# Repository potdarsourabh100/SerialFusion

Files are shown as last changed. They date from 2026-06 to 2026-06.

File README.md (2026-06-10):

# 🚀 SerialFusion

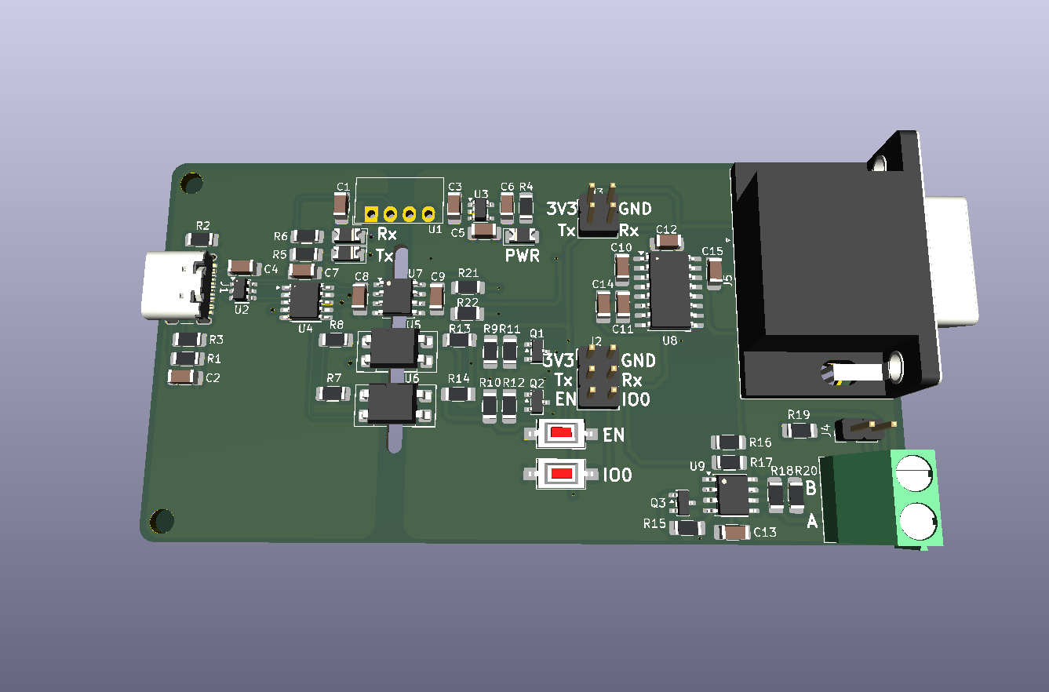
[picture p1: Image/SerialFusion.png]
3D Render


*Universal Isolated USB-to-UART / ESP32 Programmer / RS485 / RS232 Converter*

---

## 📖 Overview

**SerialFusion** is a professional-grade isolated USB communication and programming tool designed for embedded engineers, makers, students, and industrial automation developers.

The board combines multiple serial communication interfaces into a single compact device:

* USB ↔ UART (TTL/CMOS)
* ESP32 Auto Programmer
* USB ↔ RS485 Converter
* USB ↔ RS232 Converter

At its core is the reliable **CH340K USB-UART bridge**, combined with digital isolation, isolated power, industrial-grade transceivers, and ESP32 auto-programming support.

Unlike typical USB-TTL adapters, SerialFusion provides electrical isolation, industrial communication interfaces, visual status indicators, and user-friendly connectors suitable for both development and field deployment.

---

## ✨ Features

### USB-C Connectivity

* USB Type-C interface
* ESD-protected USB data lines
* Modern reversible connector
* Bus-powered operation

### Isolated UART Interface

* CH340K USB-UART bridge
* ISO7721 digital isolation
* Complete galvanic isolation between PC and target hardware
* Protection against ground loops and industrial noise

### Isolated Power Supply

* MEJ1S0505SC isolated DC-DC converter
* Independent isolated target-side supply
* Low-noise 3.3V regulation using MIC5219

### ESP32 Programming Support

* Automatic bootloader entry
* RTS → EN control
* DTR → IO0 control
* Compatible with ESP-IDF
* Compatible with Arduino IDE
* Manual BOOT and RESET pushbuttons

### RS485 Interface

* ISL3172E industrial RS485 transceiver
* Half-duplex communication
* Selectable onboard 120Ω termination resistor
* Suitable for:

  * Modbus RTU
  * EST-RBUS16
  * Custom industrial protocols
  * Multi-drop networks

### RS232 Interface

* MAX3232 RS232 transceiver
* Standard DB9 connector
* Full voltage-level conversion
* Legacy equipment compatibility

### Debugging Features

* Dedicated UART debug header
* TX activity LED
* RX activity LED
* Power indicator LED
* Clearly labeled pinout

### User-Friendly Design

* Color-coded silkscreen labels
* Compact PCB layout
* Ground-pour optimized routing
* Easy access connectors
* Professional assembly-friendly footprint selection

---

## 🔌 Interfaces

### ESP32 Programming Header

| Pin | Function |
| --- | --- |
| TX  | UART TX |
| RX  | UART RX |
| EN  | ESP32 Reset  |
| IO0 | ESP32 Boot |
| 3V3 | Target Power |
| GND | Ground |

Supports automatic firmware upload without manual button presses.

---

### UART Debug Header

| Pin | Function |
| --- | --- |
| TX  | UART TX  |
| RX  | UART RX  |
| 3V3 | Supply |
| GND | Ground |

Ideal for debugging microcontrollers and embedded systems.

---

### RS485 Connector

| Pin | Function |
| --- | --- |
| A | RS485 A  |
| B | RS485 B  |

Features selectable onboard termination resistor.

---

### RS232 Connector

Standard DB9 serial interface for legacy equipment and industrial devices.

---

## 🏗 Architecture

PC USB

↓

USB-C

↓

CH340K USB-UART

↓

ISO7721 Isolation

↓

┌─────────────┬─────────────┬─────────────┐

│ UART Debug │ ESP32 Prog │ Industrial │

│ Interface │ Interface │ Interfaces │

│ │ │ │

│ │ │ ├── RS485

│ │ │ └── RS232

└─────────────┴─────────────┴─────────────┘

---

## ⚡ Power Architecture

USB 5V

↓

MEJ1S0505SC

(Isolated DC-DC)

↓

MIC5219-3.3

↓

Isolated 3.3V Rail

This architecture provides protection against:

* Ground loops
* Industrial noise
* USB port damage
* Common-mode voltage issues

---

## 🧪 Typical Applications

### Embedded Development

* ESP32 programming
* STM32 debugging
* RP2040 development
* AVR programming
* UART monitoring

### Industrial Automation

* Modbus RTU testing
* PLC communication
* RS485 network diagnostics
* Protocol development
* Field commissioning

### Education & Learning

* Serial communication experiments
* Embedded systems labs
* Industrial communication training

---

## 🔥 Project Status

Current Stage:

**Prototype Validation**

Roadmap:

* [x] Schematic Design
* [x] PCB Layout
* [ ] Prototype Assembly
* [ ] Functional Testing
* [ ] Firmware Validation
* [ ] Production Release

---

## ❤️ Author

### EmbSysTech Innovations

**Bytes of Innovations**

Designed with passion for Embedded Systems, Industrial Electronics, and Open Hardware.

---

## ⭐ Support

If you like this project:

⭐ Star the repository

🍴 Fork the project

📢 Share with makers, students, and engineers

☕ Help spread the word about open hardware development

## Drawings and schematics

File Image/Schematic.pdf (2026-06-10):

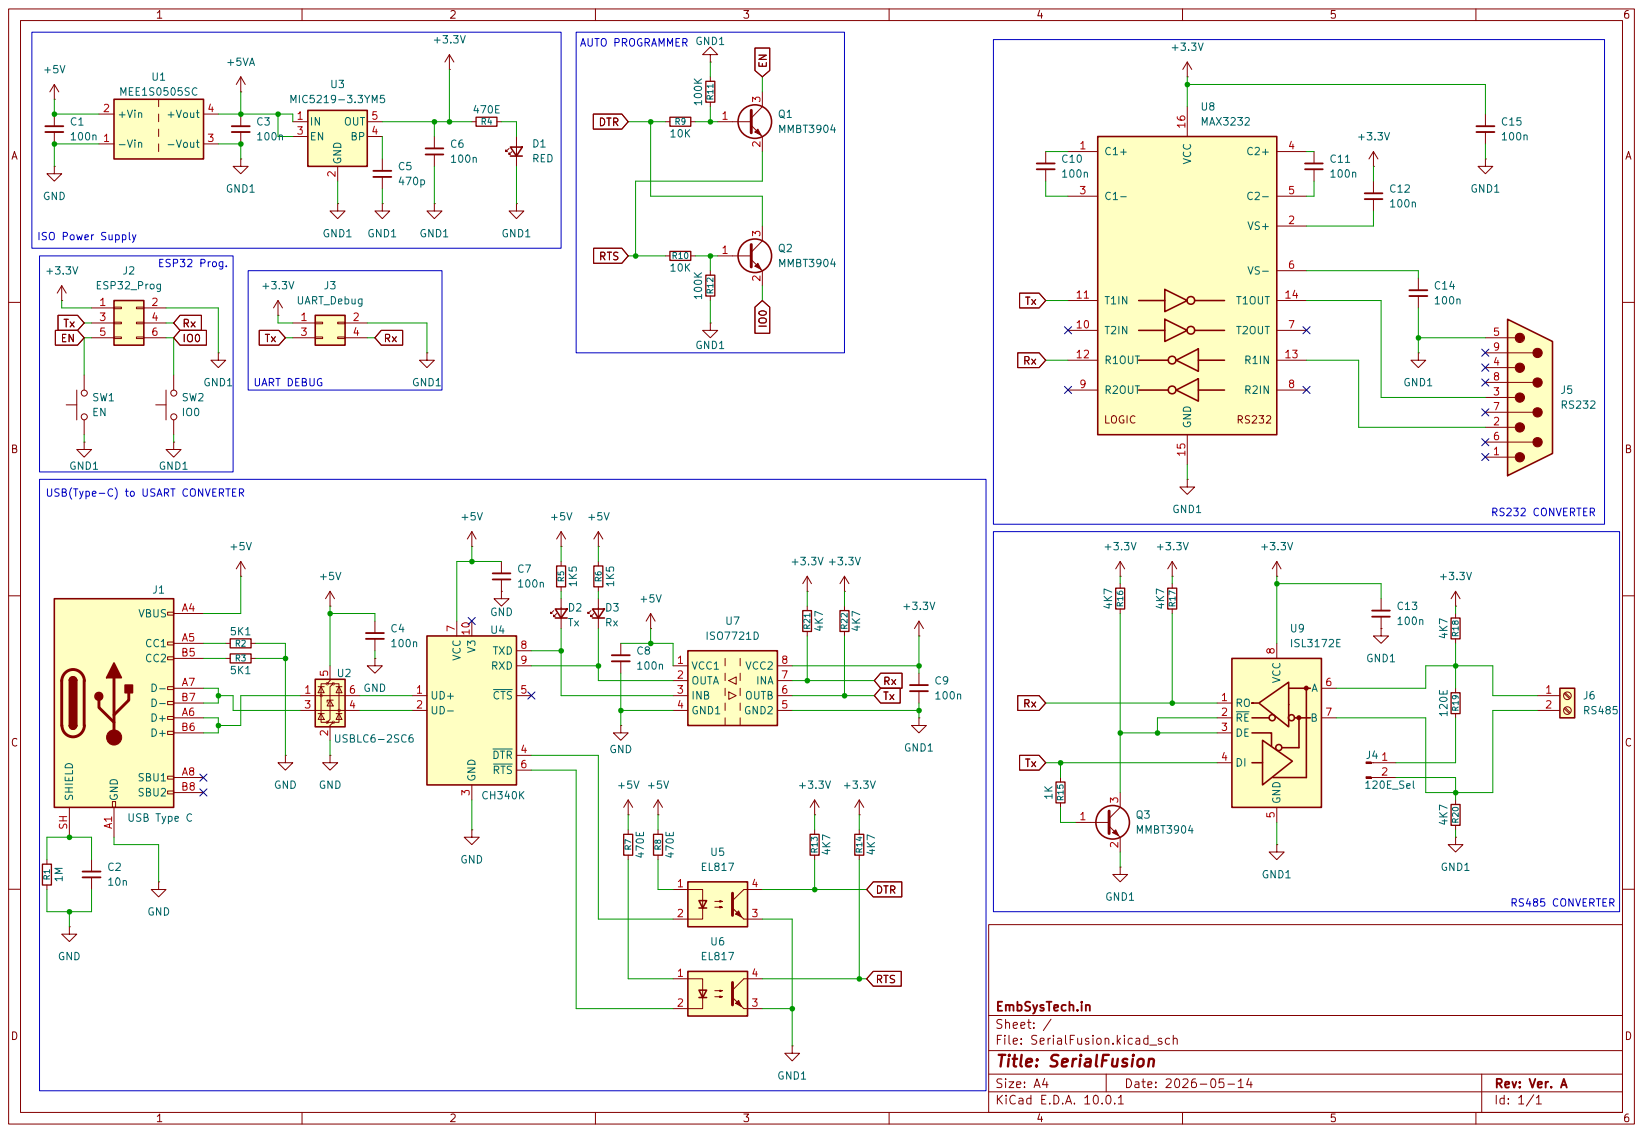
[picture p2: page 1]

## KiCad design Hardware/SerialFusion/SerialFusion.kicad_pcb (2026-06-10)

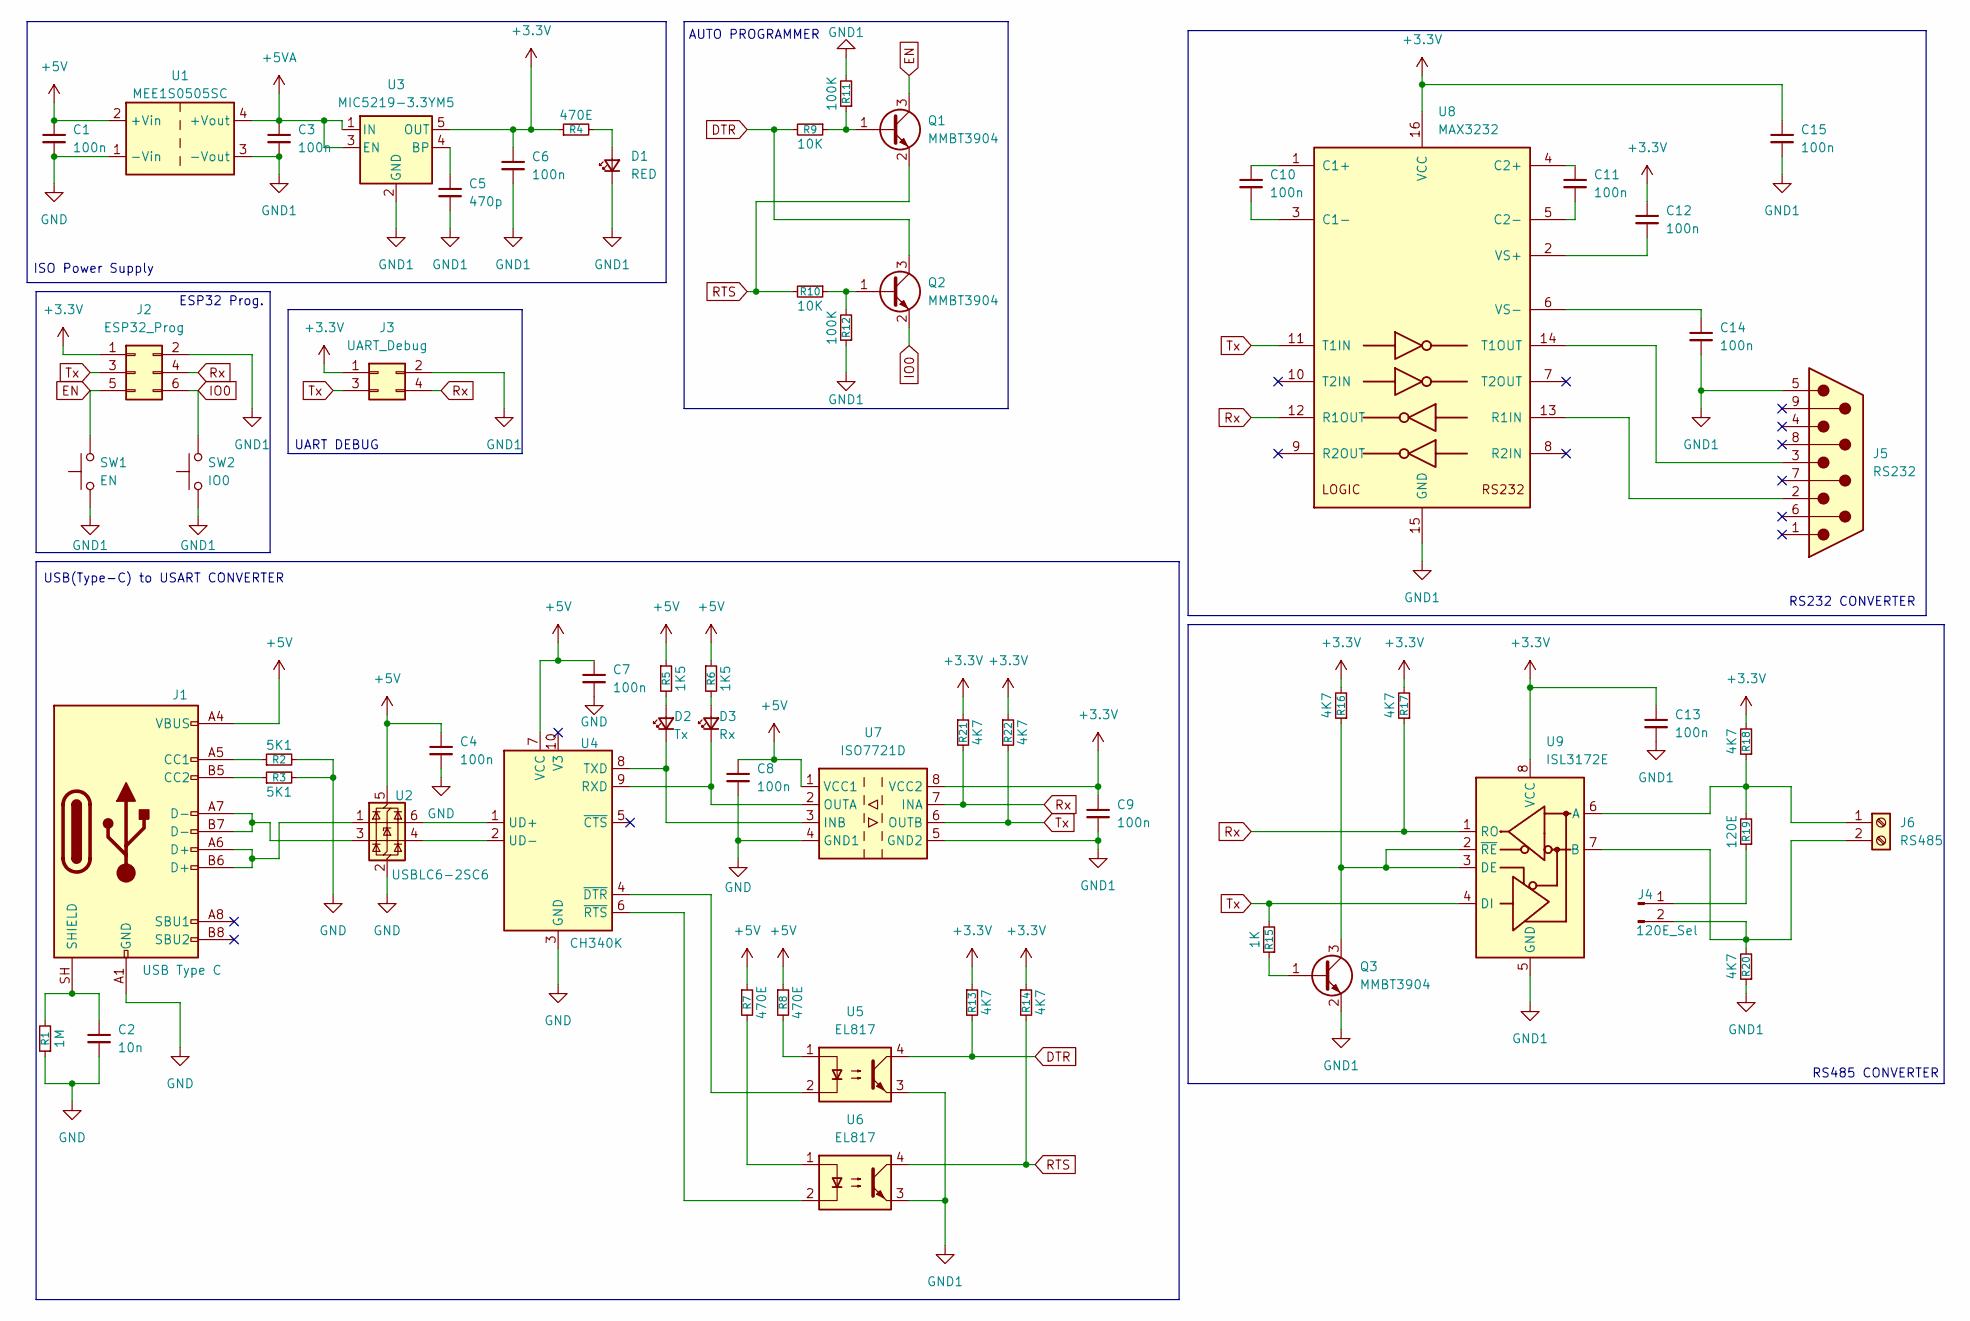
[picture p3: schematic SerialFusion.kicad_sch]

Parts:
C1, C3, C4, C6, C7, C8, C9, C10, C11, C12, C13, C14, C15: 100n; C_1206_3216Metric_Pad1.33x1.80mm_HandSolder
C2: 10n; C_1206_3216Metric_Pad1.33x1.80mm_HandSolder
C5: 470p; C_1206_3216Metric_Pad1.33x1.80mm_HandSolder
D1: RED; D_1206_3216Metric_Pad1.42x1.75mm_HandSolder
D2: Tx; D_1206_3216Metric_Pad1.42x1.75mm_HandSolder
D3: Rx; D_1206_3216Metric_Pad1.42x1.75mm_HandSolder
J1: USB Type C; USB_C_Receptacle_GCT_USB4105-xx-A_16P_TopMnt_Horizontal
J2: ESP32_Prog; PinHeader_2x03_P2.54mm_Vertical
J3: UART_Debug; PinHeader_2x02_P2.54mm_Vertical
J4: 120E_Sel; PinHeader_1x02_P2.54mm_Vertical
J5: RS232; DSUB-9_Socket_Horizontal_P2.77x2.84mm_EdgePinOffset14.56mm_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
J6: RS485; TerminalBlock_Phoenix_MKDS-1,5-2-5.08_1x02_P5.08mm_Horizont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
Q1, Q2, Q3: MMBT3904; SOT-23
R1: 1M; R_1206_3216Metric_Pad1.30x1.75mm_HandSolder
R2, R3: 5K1; R_1206_3216Metric_Pad1.30x1.75mm_HandSolder
R4, R7, R8: 470E; R_1206_3216Metric_Pad1.30x1.75mm_HandSolder
R5, R6: 1K5; R_1206_3216Metric_Pad1.30x1.75mm_HandSolder
R9, R10: 10K; R_1206_3216Metric_Pad1.30x1.75mm_HandSolder
R11, R12: 100K; R_1206_3216Metric_Pad1.30x1.75mm_HandSolder
R13, R14, R16, R17, R18, R20, R21, R22: 4K7; R_1206_3216Metric_Pad1.30x1.75mm_HandSolder
R15: 1K; R_1206_3216Metric_Pad1.30x1.75mm_HandSolder
R19: 120E; R_1206_3216Metric_Pad1.30x1.75mm_HandSolder
SW1: EN; SW_SPST_CK_RS282G05A3
SW2: IO0; SW_SPST_CK_RS282G05A3
U1: MEE1S0505SC; Converter_DCDC_Murata_MEE1SxxxxSC_THT
U2: USBLC6-2SC6; SOT-23-6
U3: MIC5219-3.3YM5; SOT-23-5
U4: CH340K; SSOP-10-1EP_3.9x4.9mm_P1mm_EP2.1x3.3mm
U5, U6: EL817; DIP-4_W7.62mm_SMDSocket_SmallPads
U7: ISO7721D; SOIC-8_3.9x4.9mm_P1.27mm
U8: MAX3232; SOIC-16W_5.3x10.2mm_P1.27mm
U9: ISL3172E; SOIC-8_3.9x4.9mm_P1.27mm

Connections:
+3.3V: C6.1, C9.1, C12.1, C13.1, C15.1, J2.1, J3.1, R4.1, R13.1, R14.1, R16.2, R17.2, R18.2, R21.1, R22.1, U3.5 (OUT), U7.8 (VCC2), U8.16 (VCC), U9.8 (VCC)
+5V: C1.1, C4.1, C7.1, C8.1, J1.A4 (VBUS), J1.A9 (VBUS), J1.B4 (VBUS), J1.B9 (VBUS), R5.1, R6.1, R7.1, R8.1, U1.2 (+Vin), U2.5 (VBUS), U4.7 (VCC), U7.1 (VCC1)
+5VA: C3.1, U1.4 (+Vout), U3.1 (IN), U3.3 (EN)
DTR: Q2.3 (C), R9.2, R13.2, U5.4
EN: J2.5, Q1.3 (C), SW1.2
GND: C1.2, C2.2, C4.2, C7.2, C8.2, J1.A1 (GND), J1.A12 (GND), J1.B1 (GND), J1.B12 (GND), R1.1, R2.2, R3.2, U1.1 (-Vin), U2.2 (GND), U4.3 (GND), U4.11 (GND), U7.4 (GND1)
GND1: C3.2, C5.2, C6.2, C9.2, C13.2, C14.2, C15.2, D1.1 (K), J2.2, J3.2, J5.5, Q3.2 (E), R11.2, R12.1, R20.1, SW1.1, SW2.1, U1.3 (-Vout), U3.2 (GND), U5.3, U6.3, U7.5 (GND2), U8.15 (GND), U9.5 (GND)
IO0: J2.6, Q2.2 (E), SW2.2
unnamed: D1.2 (A), R4.2
unnamed: D2.2 (A), R5.2
unnamed: D2.1 (K), U4.8 (TXD), U7.3 (INB)
unnamed: D3.2 (A), R6.2
unnamed: D3.1 (K), U4.9 (RXD), U7.2 (OUTA)
unnamed: J1.A5 (CC1), R2.1
unnamed: J1.B5 (CC2), R3.1
unnamed: J1.A6 (D+), J1.B6 (D+), U2.1 (I/O1)
unnamed: J1.A7 (D-), J1.B7 (D-), U2.3 (I/O2)
unnamed: C2.1, J1.SH (SHIELD), R1.2
unnamed: J4.1, R19.1
unnamed: J4.2, J6.2, R20.2, U9.7 (B)
unnamed: J6.1, R18.1, R19.2, U9.6 (A)
unnamed: Q1.1 (B), R9.1, R11.1
unnamed: Q2.1 (B), R10.1, R12.2
unnamed: Q3.1 (B), R15.1
unnamed: Q3.3 (C), R16.1, U9.2 (~RE), U9.3 (DE)
unnamed: R7.2, U6.1
unnamed: R8.2, U5.1
unnamed: C5.1, U3.4 (BP)
unnamed: U2.6 (I/O1), U4.1 (UD+)
unnamed: U2.4 (I/O2), U4.2 (UD-)
unnamed: U4.4 (~DTR), U5.2
unnamed: U4.6 (~RTS), U6.2
unnamed: C10.1, U8.1 (C1+)
unnamed: C10.2, U8.3 (C1-)
unnamed: C11.1, U8.4 (C2+)
unnamed: C11.2, U8.5 (C2-)
unnamed: J5.2, U8.13 (R1IN)
unnamed: J5.3, U8.14 (T1OUT)
unnamed: C12.2, U8.2 (VS+)
unnamed: C14.1, U8.6 (VS-)
RTS: Q1.2 (E), R10.2, R14.2, U6.4
Rx: J2.4, J3.4, R17.1, R21.2, U7.7 (INA), U8.12 (R1OUT), U9.1 (RO)
Tx: J2.3, J3.3, R15.2, R22.2, U7.6 (OUTB), U8.11 (T1IN), U9.4 (DI)

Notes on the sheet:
RS485 CONVERTER
AUTO PROGRAMMER
ISO Power Supply
USB(Type-C) to USART CONVERTER
ESP32 Prog.
UART DEBUG
RS232 CONVERTER

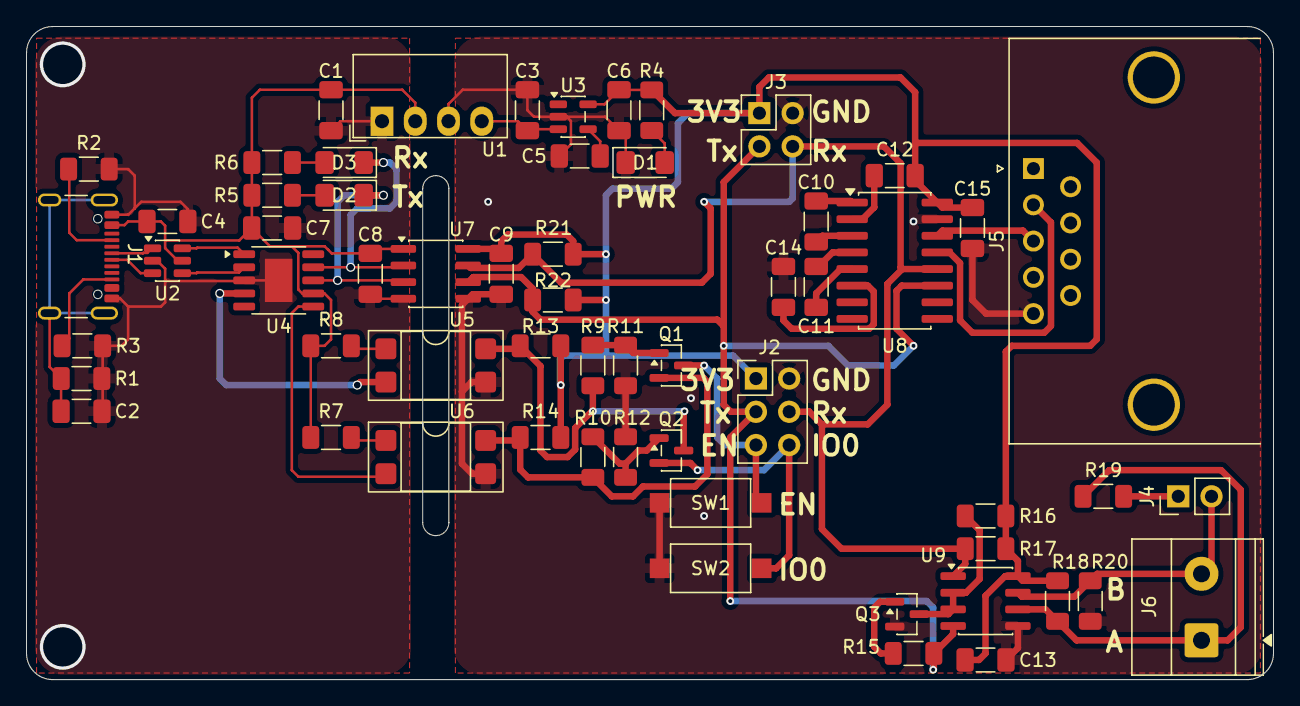
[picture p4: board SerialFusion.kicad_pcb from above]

Board: 2 copper layers, 95.3 x 49.9 mm, 60 parts (0 on the bottom side), 43 nets.

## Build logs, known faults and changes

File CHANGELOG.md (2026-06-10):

# Changelog

All notable changes to this project will be documented in this file.

The format follows Keep a Changelog principles.

---

## [0.1.0] - 2026-05-14

### Added

#### Core Hardware

* CH340K USB-to-UART bridge
* USB Type-C interface
* USB ESD protection circuitry
* TX/RX activity indicators
* Power status LED

#### Isolation

* ISO7721 digital isolator
* MEJ1S0505SC isolated DC-DC converter
* MIC5219 3.3V regulator
* Fully isolated target-side UART

#### ESP32 Support

* Dedicated ESP32 programming header
* Auto-programming circuit using RTS/DTR
* EN reset control
* IO0 boot control
* Reset pushbutton
* Boot pushbutton

#### RS485 Interface

* ISL3172E RS485 transceiver
* Selectable 120Ω termination resistor
* Industrial communication support

#### RS232 Interface

* MAX3232 RS232 transceiver
* DB9 serial connector

#### Debug Features

* Dedicated UART debug header
* Clearly labeled connectors
* Color-coded silkscreen markings

### PCB

* Compact PCB layout
* Ground-pour optimization
* Isolation barrier implementation
* Manufacturing-ready design

### Documentation

* Initial project documentation
* Interface descriptions
* Hardware architecture overview

---

## Upcoming

### Planned for v0.2.0

* Prototype validation results
* Communication performance measurements
* Isolation testing report
* RS485 interoperability testing
* ESP32 programming verification
* Manufacturing notes

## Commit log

2026-05-14 Intermediate release with Schematic in progress as well as README.md is under changes
    [SerialFusion.kicad_pcb, SerialFusion.kicad_sch]
2026-06-10 First stage design for Rev A is completed & files updated
    [SerialFusion-B_Cu.gbr, SerialFusion-B_Mask.gbr, SerialFusion-B_Paste.gbr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]
